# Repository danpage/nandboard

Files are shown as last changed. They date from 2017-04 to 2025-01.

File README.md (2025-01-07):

# NANDboard: hands-on Boolean algebra

<!--- -------------------------------------------------------------------- --->

## History

Starting in the 2012/13 academic year, the
[Computer Science Department](http://www.cs.bris.ac.uk)
at the
[University of Bristol](http://www.bris.ac.uk)
changed how the Undergraduate-level, 1st year (or "freshman") Computer
Architecture unit was delivered.  Although it *always* had a practical
emphasis, there was a view it should be even more hands-on.
There were various motivations, included the fact that
a) by doing so the topic could be more engaging,
   but also
b) it seeds an ethos and skills that are of general use: for example,
   it could mean students participate more actively in
   [maker-like](http://en.wikipedia.org/wiki/Maker_culture),
   hardware-based (versus software-only) projects.

The NANDboard, whose original concept and design was due to
[Simon Hollis](https://github.com/simonhollis),
was among various innovations introduced; Simon left at the end of the
2014/15 academic year, ~~prompting~~ forcing me to learn the basics of
PCB design and subsequently revise his initial NANDboard version.

<!--- -------------------------------------------------------------------- --->

## Concept

Although fundamentally important in Computer Science,
[Boolean algebra](http://en.wikipedia.org/wiki/Boolean_algebra)
is a notoriously dry topic.  The problem is exacerbated when hands-on 
experience amounts to solving paper-and-pencil exercises; the typical
result is for students to be increasingly uninterested and disengaged.
The underlying causes are varied, and differ from student to student.
However, anecdotally at least, the following are common:

- There is a disconnection between theory and practice, in the sense
  it is unclear how Boolean algebra directly relates to intuitively 
  useful forms of computation;
  this typically leads to students disengaging,
  based on the view that said theory has no practical use (to them).
- Paper-and-pencil exercises are of a necessarily small scale, which
  can mean 
  [toy problems](http://en.wikipedia.org/wiki/Toy_problem)
  dominate; 
  this typically leads to students disengaging, e.g., because they
  can easily solve said problems so avoid any deeper investigation
  of physical constraints and properties, and unusual designs
  (e.g., a [C-element](https://en.wikipedia.org/wiki/C-element)).
- In part due to the wealth of resources available, modern students 
  are used to and excited by the immediacy of software development;
  this is often direct motivation for studying Computer Science in 
  the first place, with Boolean algebra feeling like a regression 
  towards Mathematics (which, for some, is less popular).

Put another way, this approach is similar, by analogy, to learning
[C](http://en.wikipedia.org/wiki/C_(programming_language))
by studying the language and 
["hello world"](https://en.wikipedia.org/wiki/"Hello,_World!"_program)
style programs *without* ever actually compiling and executing them.

An obvious alternative is to connect theory and practice directly, by
supporting genuinely hands-on, experimental tasks.  One way to do so
might be to equip each student with a breadboard and some
[7400 series](https://en.wikipedia.org/wiki/List_of_7400_series_integrated_circuits)
ICs.  However, for us at least, this presented some problems:
a) large cohort sizes
   (of say 200+ students)
   make the logistics involved quite challenging,
b) said cohorts are typically unfamiliar with, and sometimes have an
   outright dislike for electronics.
The NANDboard attempts to manage these problems.  Conceptually, it is 
just a USB-powered breadboard pre-populated with NAND gates: it could
be viewed as a form of NAND-only
[PLA](http://en.wikipedia.org/wiki/Programmable_logic_array),
where implementation of a Boolean expression (cf. programming the PLA)
amounts to connecting pin headers (i.e., the gate inputs and outputs)
using jumper wire.  There are, of course, some gratuitous
[blinkenlights](http://en.wikipedia.org/wiki/Blinkenlights)
to visualise the inputs and outputs.

<!--- -------------------------------------------------------------------- --->

## Design

Motivated in part by observing how students use them, the NANDboard 
design has gone through several revisions as is illustrated below:

Revision | Image                                                                             | Design                                                                             |
:------: | :-------------------------------------------------------------------------------: | :--------------------------------------------------------------------------------: |
B        |  |                                                                                    |
C        |  |                                                                                    |
D        |  | [files](./rev_d), [schematic](./rev_d/README.pdf), [user guide](./rev_d/README.md) |
F        |  | [files](./rev_f), [schematic](./rev_f/README.pdf), [user guide](./rev_f/README.md) |

<!--- -------------------------------------------------------------------- --->

## Acknowledgements

Later revisions 
(e.g., rev. F) 
were designed and manufactured with generous support from 
[Elliptic Systems](https://elliptic-systems.com).

<!--- -------------------------------------------------------------------- --->

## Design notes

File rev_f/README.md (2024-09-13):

<!--- -------------------------------------------------------------------- --->

# High-level structure

At a high level, (the top-side of) a given 
NANDboard
is organised into a set of somewhat groups (or regions) reflected 
by annotation on the 
[PCB](https://en.wikipedia.org/wiki/Printed_circuit_board):

```
+----------+----------+----------+----------+----------+
|    input |     NAND |     NAND |   output |    power |
|    group |    group |    group |    group |    group |
|          |       #0 |       #1 |          |          |
|          +----------+----------+          |          |~~~~ USB
|          |     NAND |     NAND |          |          |
|          |    group |    group |          |          |
|          |       #2 |       #3 |          |          |
+----------+----------+----------+----------+----------+
```

Each group designed to support a specific purpose, as explained
in detail below.  Again
at a high level,
however, use of the 
NANDboard 
can be summarised as follows.  Imagine you are tasked with using 
a
NANDboard
to implement some 4-input, 1-output Boolean function
`R = f( X_0, X_1, X_2, X_3 )`
To do so, the idea is you

- use the  input group  to model (and   control) the  input, 
- use the   NAND groups to implement `f` by decomposing it into a NAND-based expression,
- use the output group  to model (and visualise) the output, 
  
using
[jumper wire](https://en.wikipedia.org/wiki/Jump_wire)
to form connections to inputs, outputs, and between intermediate 
signals.

<!--- -------------------------------------------------------------------- --->

# Low-level detail

### The power    group

Viewed from top-to-bottom,
the  power  group comprises

- an 8x2          [pin header](https://en.wikipedia.org/wiki/Pin_header),
- a type-C [USB](https://en.wikipedia.org/wiki/USB) connector,
- an 8x2          [pin header](https://en.wikipedia.org/wiki/Pin_header).

The basic idea is that:

- The USB connector 
  supplies the 
  NANDboard 
  with power from some host (e.g., a workstation).
- The pin headers allow multiple 
  NANDboards 
  to be
  ["daisy-chained"](https://en.wikipedia.org/wiki/Daisy_chain_(electrical_engineering))
  together, e.g., to implement larger, more complex designs: doing
  so basically means 
  
  - supplying *one*
    "powered"  NANDboard 
    with power via the USB connector
  - supplying *other*
    "tethered" NANDboards
    with power via their pin headers by connecting their
     [5V](https://en.wikipedia.org/wiki/Volt)
    and
    [GND](https://en.wikipedia.org/wiki/Ground_(electricity))
    pins to those of the
    "powered"  NANDboard.

  This demands care, however, because misconnection can potentially 
  damage the board and/or workstation: the safest approach would be
  to cover the pins with
  [jumpers](https://en.wikipedia.org/wiki/Jumper_(computing))
  when not in use.

### The input    group

Viewed from left-to-right, 
the   input group comprises

- 4 [switches](http://en.wikipedia.org/wiki/Switch) (or buttons),
  and
- an 8x2          [pin header](https://en.wikipedia.org/wiki/Pin_header).

so can be thought of conceptually as the following block diagram:
   
```
switches           pins 
 __|__         _____|_____ 
/     \       /           \
               +-----+-----+
+-----+       | X_0 | X_0 |
| X_0 | ~~~>  +-----+-----+
+-----+       | X_0 | X_0 |
              +-----+-----+
+-----+       | X_1 | X_1 |
| X_1 | ~~~>  +-----+-----+
+-----+       | X_1 | X_1 |
              +-----+-----+
+-----+       | X_2 | X_2 |
| X_2 | ~~~>  +-----+-----+
+-----+       | X_2 | X_2 |
              +-----+-----+
+-----+       | X_3 | X_3 |
| X_3 | ~~~>  +-----+-----+
+-----+       | X_3 | X_3 |
              +-----+-----+
```

The basic idea is that
each switch is connected to a group of 4 pins:
the state of each group of pins (i.e., 0 or 1)
is determined by
that of the associated switch,
so when the switch is pressed (resp. not pressed) the pins will be 1 (resp. 0).

### The output   group

Viewed from left-to-right, 
the  output group comprises

- an 8x2          [pin header](https://en.wikipedia.org/wiki/Pin_header),
  and
- 4 [LEDs](https://en.wikipedia.org/wiki/Light-emitting_diode).

```
     pins            LEDs
 _____|_____        __|__
/           \      /     \

+-----+-----+
| R_0 | R_0 |      +-----+
+-----+-----+ ~~~> | R_0 |
| R_0 | R_0 |      +-----+
+-----+-----+
| R_1 | R_1 |      +-----+
+-----+-----+ ~~~> | R_1 | 
| R_1 | R_1 |      +-----+
+-----+-----+
| R_2 | R_2 |      +-----+
+-----+-----+ ~~~> | R_2 |
| R_2 | R_2 |      +-----+
+-----+-----+
| R_3 | R_3 |      +-----+
+-----+-----+ ~~~> | R_3 |
| R_3 | R_3 |      +-----+
+-----+-----+
```

The basic idea is that
each LED    is connected to a group of 4 pins:
the state of each group of pins (i.e., 0 or 1)
determines
that of the associated LED,
so when the pins are 1 (resp. 0) the LED will be on (resp. off).

## The NAND     group(s)

Viewed from left-to-right, 
each NAND   group comprises

- an 4x2 constant [pin header](https://en.wikipedia.org/wiki/Pin_header),
- an 8x2    input [pin header](https://en.wikipedia.org/wiki/Pin_header),
- an [IC](http://www.ti.com/lit/gpn/sn74ac00) that houses 4 [NAND gates](https://en.wikipedia.org/wiki/NAND_gate),
- an 8x2   output [pin header](https://en.wikipedia.org/wiki/Pin_header).
  and
- 4 [LEDs](https://en.wikipedia.org/wiki/Light-emitting_diode).

so can be thought of conceptually as the following block diagram:

```
constant pins
 _____|_____
/           \

+-----+-----+
|  1  |  1  |
+-----+-----+
|  1  |  1  |
+-----+-----+

 input pins                NAND gates             output pins         LEDs
 _____|_____        ___________|__________        _____|_____        __|__
/           \      /                      \      /           \      /     \

+-----+-----+      +----------------------+      +-----+-----+
| x_0 | x_0 | ~~~> |                      |      | r_0 | r_0 |      +-----+
+-----+-----+      | r_0 = ~( x_0 & y_0 ) | ~~~> +-----+-----+ ~~~> | r_0 |
| y_0 | y_0 | ~~~> |                      |      | r_0 | r_0 |      +-----+
+-----+-----+      |                      |      +-----+-----+
| x_1 | x_1 | ~~~> |                      |      | r_1 | r_1 |      +-----+
+-----+-----+      | r_1 = ~( x_1 & y_1 ) | ~~~> +-----+-----+ ~~~> | r_1 |
| y_1 | y_1 | ~~~> |                      |      | r_1 | r_1 |      +-----+
+-----+-----+      |                      |      +-----+-----+
| x_2 | x_2 | ~~~> |                      |      | r_2 | r_2 |      +-----+
+-----+-----+      | r_2 = ~( x_2 & y_2 ) | ~~~> +-----+-----+ ~~~> | r_2 |
| y_2 | y_2 | ~~~> |                      |      | r_2 | r_2 |      +-----+
+-----+-----+      |                      |      +-----+-----+
| x_3 | x_3 | ~~~> |                      |      | r_3 | r_3 |      +-----+
+-----+-----+      | r_3 = ~( x_3 & y_3 ) | ~~~> +-----+-----+ ~~~> | r_3 |
| y_3 | y_3 | ~~~> |                      |      | r_3 | r_3 |      +-----+
+-----+-----+      +----------------------+      +-----+-----+
```
   
The basic idea is that:

- Each group houses 4 replicated instances of the same structure,
  the `i`-th of which computes 
  `r_i = ~( x_i & y_i )`.
  We use on the 0-th, top-most instance as an example throughout
  the following.  

- The computation of
  `r_0 = ~( x_0 & y_0 )`
  relates to the top 4 pins (i.e., top 2 rows) of both the input
  and output pins headers: the input pins marked `x_0` and `y_0` 
  provided an input to the NAND gate, which produces a result 
  reflected on the output pins marked `r_0`.  
  Each output pin is also connected to an LED, allowing the state
  (i.e., 0 or 1) to be visualised.

- Note there are 2 pins marked `x_0` and `y_0` on the input pin
  header: since they are connected together, either of the 2 pins
  (i.e., the left- *or* right-hand pin marked `x_0`) can be used 
  to provide the associated input.  Likewise, there are 4 pins
  marked `r_0` on the output pin header: the NAND gate output is
  replicated on each of those pins.

- Each input pin is 
  [pulled-down](http://en.wikipedia.org/wiki/Pull-up_resistor), 
  meaning that `x_0` and `y_0` are 0 and `r_0` is 1 by default.
  However, an input pin can be freely connected (via jumper wire)
  to any other

  - constant           pin,
  - input group        pin,
  - NAND  group input  pin,
  - NAND  group output pin

  elsewhere on the NANDboard.

- Since each input pin is 0-by-default, the constant pins can be
  used to "override" this.  Imagine that rather than
  `r_0 = ~( x_0 & y_0 )`,
  you need to compute
  `r_0 = ~( x_0 & 1   )`
  for some reason: a reasonable approach is to connect the `y_0` 
  input pin of the NAND gate to one of the 1-by-default constant
  pins.

- The NAND groups and hence operators are independent, meaning 
  you can form inter- and intra-group connections (i.e., inside 
  one group and between two groups).

### Misc.

The bottom-side of the
NANDboard
includes a
10-pin [TagConnect](https://www.tag-connect.com)
header: those pins connect to

- the 
  [5V](https://en.wikipedia.org/wiki/Volt)
  and
  [GND](https://en.wikipedia.org/wiki/Ground_(electricity))
  pins in the  power group,
- each 
  pin  in the  input group, i.e., `X_0`, `X_1`, `X_2`, and `X_3`,
  and
- each 
  pin  in the output group, i.e., `R_0`, `R_1`, `R_2`, and `R_3`.

By connecting the
NANDboard
to a host using a compliant
[pogo-pin](https://en.wikipedia.org/wiki/Pogo_pin) 
style cable, one can therefore programmatically control input to
and inspect output generated by it; an example use-case would be
to automatically, and exhaustively test whether the
NANDboard 
correctly implements a given function.

<!--- -------------------------------------------------------------------- --->

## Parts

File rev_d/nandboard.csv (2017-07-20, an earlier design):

Qty | Line Item | Manufacturer | Schematic Reference | Description
4 | SN74AC00DR | Texas Instruments | IC1.1, IC2.1, IC3.1, IC4.1 | quad 2-input NAND; SOIC-14
4 | B3FS-1000P | Omron | SI.1, SI.2, SI.3, SI.4 | SPST switch
1 | 10103594-0001LF | FCI | USB | USB receptacle
9 | M20-8760842 | Harwin | J1.1, J1.2, J2.1, J2.2, J3.1, J3.2, J4.1, J4.2, JI.1 | 8x2 male header
4 | M20-8770842 | Harwin | J1.3, J2.3, J3.3, J4.3 | 8x1 male header
16 | APT2012SGC | Kingbright | D1.1, D1.2, D1.3, D1.4, D2.1, D2.2, D2.3, D2.4, D3.1, D3.2, D3.3, D3.4, D4.1, D4.2, D4.3, D4.4 | green LED; 0805
1 | C1210C107M9PACTU | KEMET | CP.1 | 100 uF capacitor; 1210
1 | C0805C104K3RACTU | KEMET | CP.2 | 100 nF = 0.1 uF capacitor; 0805
4 | 742C163103JP | CTS Components | R1.1, R2.1, R3.1, R4.1 | 8x10k ohm resistor array; 2506
1 | 742C083103JP | CTS Components | RI.1 | 4x10k ohm resistor array; 1206
4 | 742C083561JP | CTS Components | R1.2, R2.2, R3.2, R4.2 | 4x560 ohm resistor array; 1206
4 | 742C083102JP | CTS Components | R1.3, R2.3, R3.3, R4.3 | 4x1k ohm resistor array; 1206

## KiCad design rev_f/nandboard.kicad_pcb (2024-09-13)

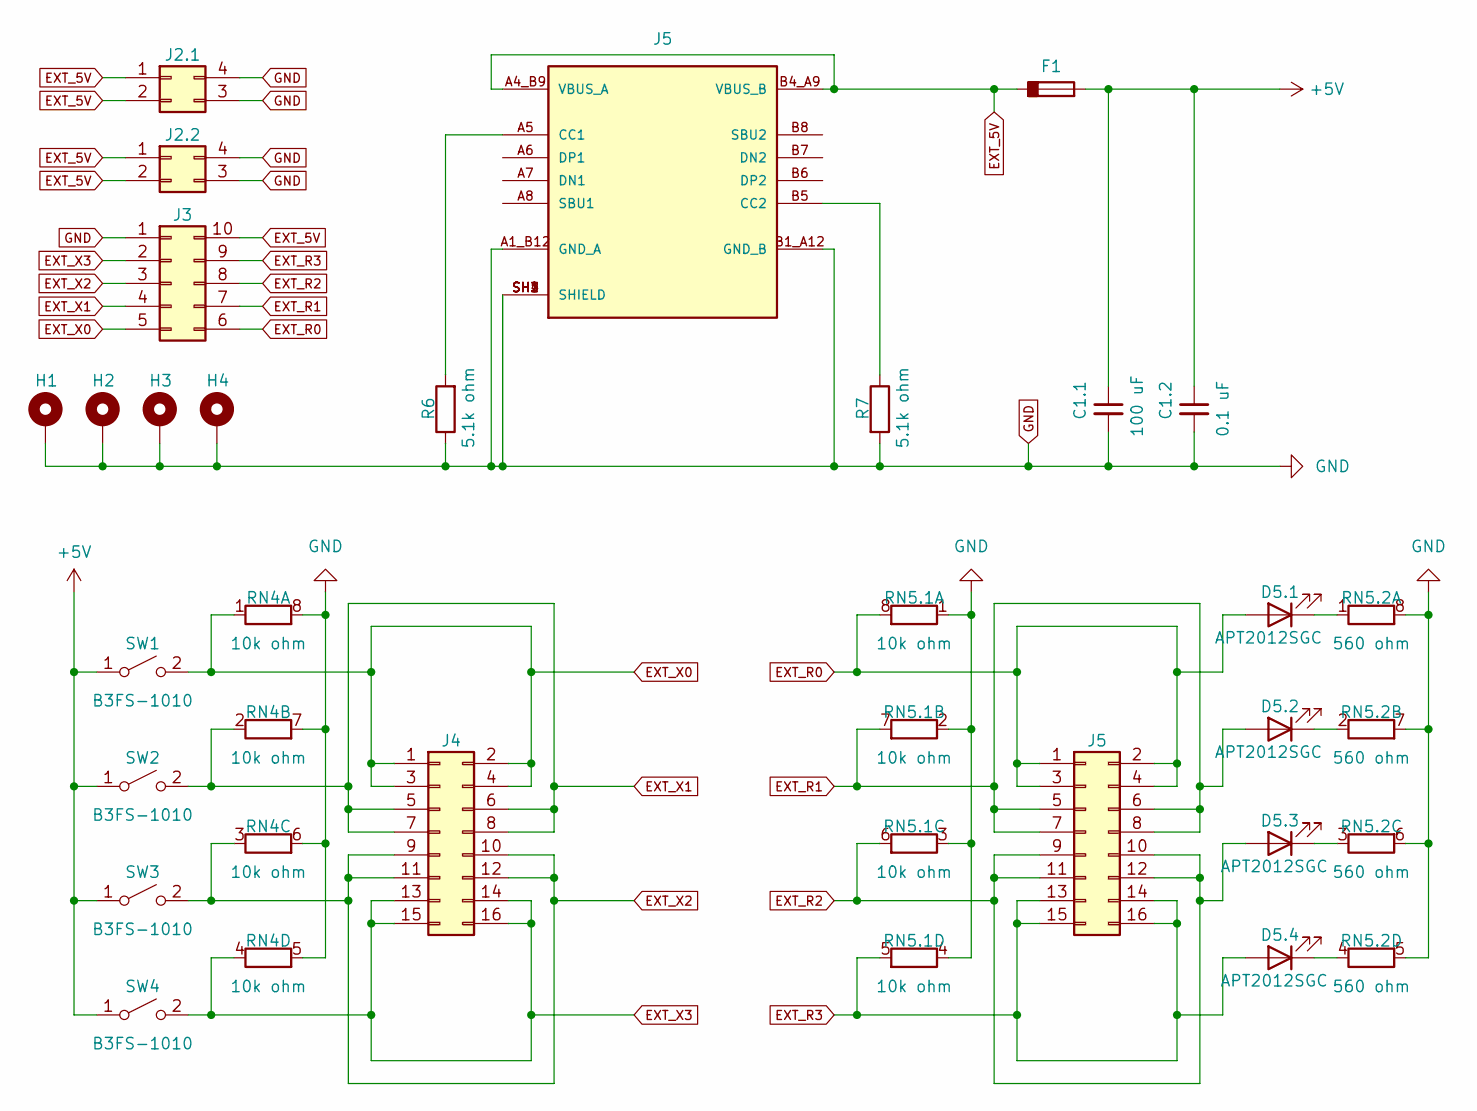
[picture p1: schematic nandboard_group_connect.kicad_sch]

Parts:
C1.1: 100 uF; C_1210_3225Metric
C1.2: 0.1 uF; C_0805_2012Metric
D5.1, D5.2, D5.3, D5.4: APT2012SGC; LED_0805_2012Metric
F1: Fuse_Polarized; Fuse_1206_3216Metric
H1, H2, H3, H4: MountingHole_Pad; MountingHole_3.2mm_M3_Pad
J2.1, J2.2: Conn_02x02_Counter_Clockwise; PinHeader_2x02_P2.54mm_Vertical_SMD
J3: Conn_02x05_Counter_Clockwise; Tag-Connect_TC2050-IDC-NL_2x05_P1.27mm_Vertical
J4: Conn_02x08_Odd_Even; PinHeader_2x08_P2.54mm_Vertical_SMD
J5: USB_C_Receptacle_USB2.0; AMPHENOL_GSB1C41110SSHR; Mouser Part Number 523-GSB1C41110SSHR
R6, R7: 5.1k ohm; R_0603_1608Metric; Mouser Part Number 755-SFR18EZPF5101
RN4, RN5.1: 10k ohm; RN-1206-Convex-LongSideTerminals
RN5.2: 560 ohm; RN-1206-Convex-LongSideTerminals
SW1, SW2, SW3, SW4: B3FS-1010; SW_SPST_Omron_B3FS-101xP

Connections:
+5V: C1.1.1, C1.2.1, F1.2, SW1.1 (A), SW2.1 (A), SW3.1 (A), SW4.1 (A); also elsewhere on the board
EXT_5V: F1.1, J2.1.1, J2.1.2, J2.2.1, J2.2.2, J3.10, J5.A4_B9 (VBUS_A), J5.B4_A9 (VBUS_B); also elsewhere on the board
EXT_R0: D5.1.2 (A), J3.6, J5.1, J5.2, J5.3, J5.4, RN5.1.8 (R1.2)
EXT_R1: D5.2.2 (A), J3.7, J5.5, J5.6, J5.7, J5.8, RN5.1.7 (R2.2)
EXT_R2: D5.3.2 (A), J3.8, J5.9, J5.10, J5.11, J5.12, RN5.1.6 (R3.2)
EXT_R3: D5.4.2 (A), J3.9, J5.13, J5.14, J5.15, J5.16, RN5.1.5 (R4.2)
EXT_X0: J3.5, J4.1, J4.2, J4.3, J4.4, RN4.1 (R1.1), SW1.2 (B)
EXT_X1: J3.4, J4.5, J4.6, J4.7, J4.8, RN4.2 (R2.1), SW2.2 (B)
EXT_X2: J3.3, J4.9, J4.10, J4.11, J4.12, RN4.3 (R3.1), SW3.2 (B)
EXT_X3: J3.2, J4.13, J4.14, J4.15, J4.16, RN4.4 (R4.1), SW4.2 (B)
GND: C1.1.2, C1.2.2, H1.1, H2.1, H3.1, H4.1, J2.1.3, J2.1.4, J2.2.3, J2.2.4, J3.1, J5.A1_B12 (GND_A), J5.B1_A12 (GND_B), J5.SH1 (SHIELD), J5.SH2 (SHIELD), J5.SH3 (SHIELD), J5.SH4 (SHIELD), RN4.5 (R4.2), RN4.6 (R3.2), RN4.7 (R2.2), RN4.8 (R1.2), RN5.1.1 (R1.1), RN5.1.2 (R2.1), RN5.1.3 (R3.1), RN5.1.4 (R4.1), RN5.2.5 (R4.2), RN5.2.6 (R3.2), RN5.2.7 (R2.2), RN5.2.8 (R1.2); also elsewhere on the board
unnamed: D5.1.1 (K), RN5.2.1 (R1.1)
unnamed: D5.2.1 (K), RN5.2.2 (R2.1)
unnamed: D5.3.1 (K), RN5.2.3 (R3.1)
unnamed: D5.4.1 (K), RN5.2.4 (R4.1)

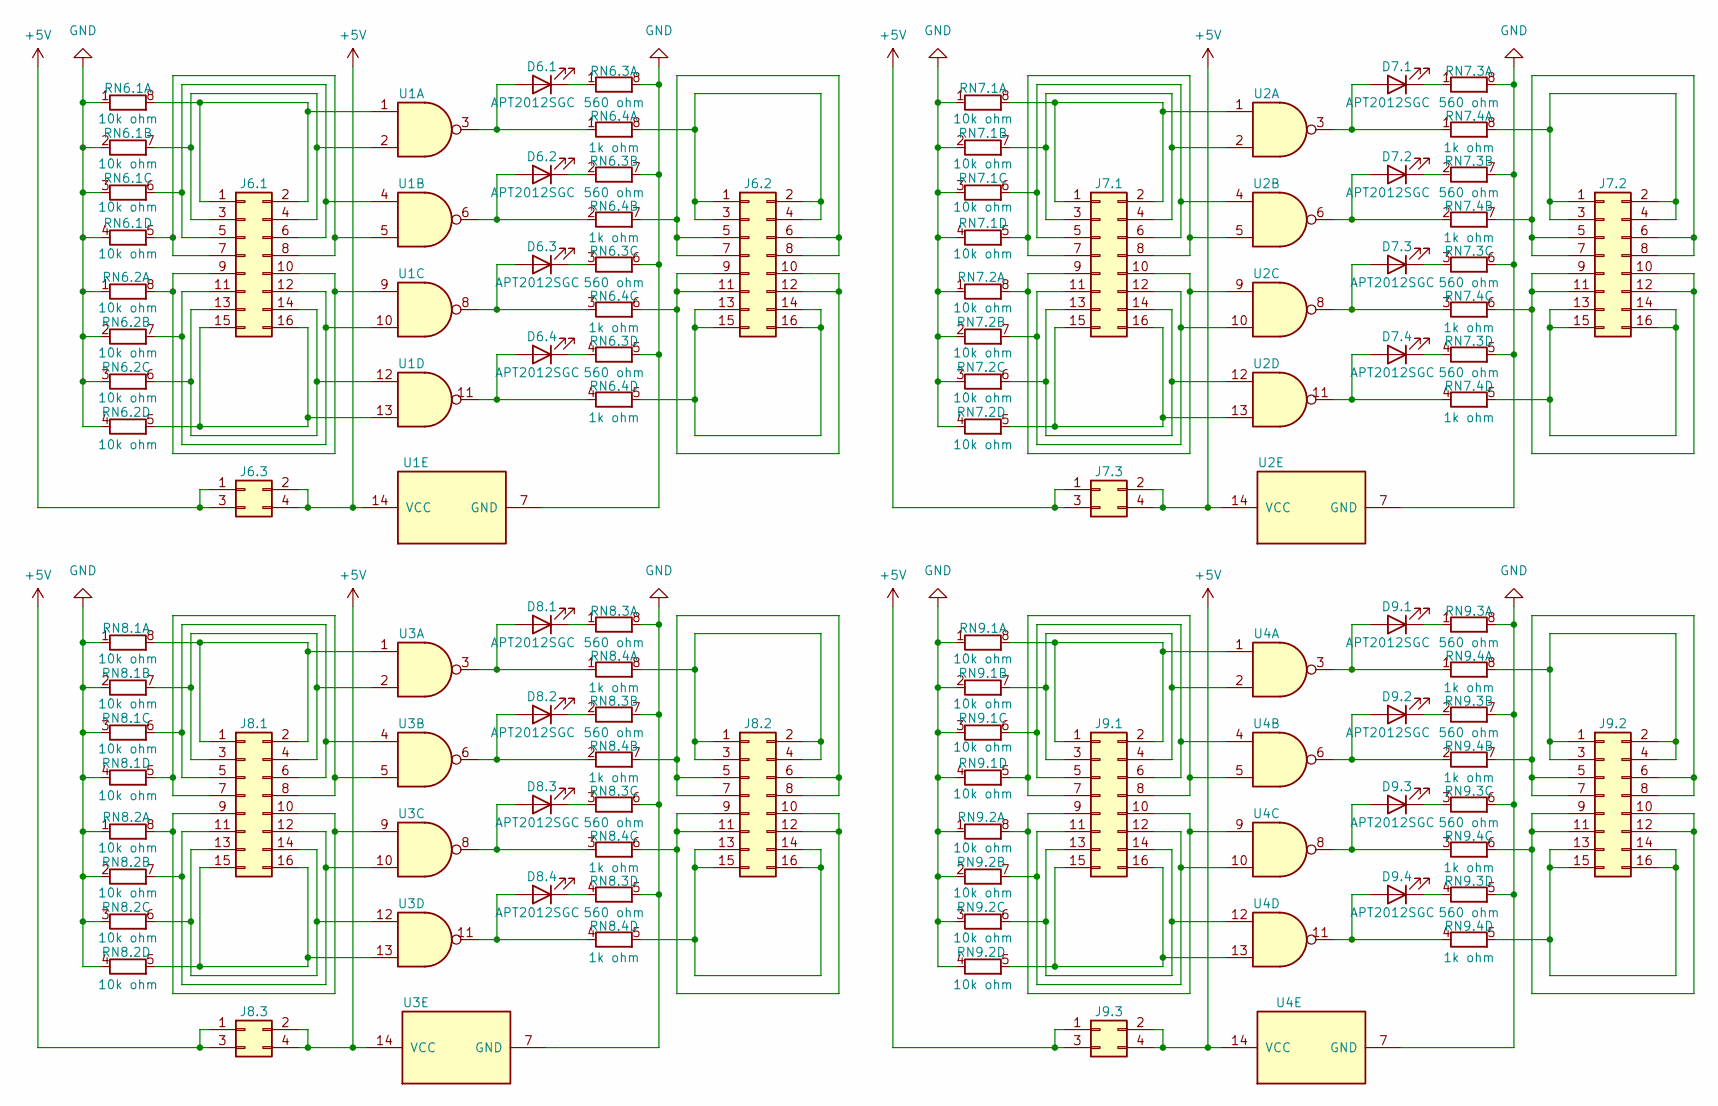
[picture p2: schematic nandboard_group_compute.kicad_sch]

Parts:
D6.1, D6.2, D6.3, D6.4, D7.1, D7.2, D7.3, D7.4, D8.1, D8.2, D8.3, D8.4, D9.1, D9.2, D9.3, D9.4: APT2012SGC; LED_0805_2012Metric
J6.1, J6.2, J7.1, J7.2, J8.1, J8.2, J9.1, J9.2: Conn_02x08_Odd_Even; PinHeader_2x08_P2.54mm_Vertical_SMD
J6.3, J7.3, J8.3, J9.3: Conn_02x02_Odd_Even; PinHeader_2x02_P2.54mm_Vertical_SMD
RN6.1, RN6.2, RN7.1, RN7.2, RN8.1, RN8.2, RN9.1, RN9.2: 10k ohm; RN-1206-Convex-LongSideTerminals
RN6.3, RN7.3, RN8.3, RN9.3: 560 ohm; RN-1206-Convex-LongSideTerminals
RN6.4, RN7.4, RN8.4, RN9.4: 1k ohm; RN-1206-Convex-LongSideTerminals
U1, U2, U3, U4: 7400; SOIC-14_3.9x8.7mm_P1.27mm

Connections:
+5V: J6.3.1, J6.3.2, J6.3.3, J6.3.4, J7.3.1, J7.3.2, J7.3.3, J7.3.4, J8.3.1, J8.3.2, J8.3.3, J8.3.4, J9.3.1, J9.3.2, J9.3.3, J9.3.4, U1.14 (VCC), U2.14 (VCC), U3.14 (VCC), U4.14 (VCC); also elsewhere on the board
GND: RN6.1.1 (R1.1), RN6.1.2 (R2.1), RN6.1.3 (R3.1), RN6.1.4 (R4.1), RN6.2.1 (R1.1), RN6.2.2 (R2.1), RN6.2.3 (R3.1), RN6.2.4 (R4.1), RN6.3.5 (R4.2), RN6.3.6 (R3.2), RN6.3.7 (R2.2), RN6.3.8 (R1.2), RN7.1.1 (R1.1), RN7.1.2 (R2.1), RN7.1.3 (R3.1), RN7.1.4 (R4.1), RN7.2.1 (R1.1), RN7.2.2 (R2.1), RN7.2.3 (R3.1), RN7.2.4 (R4.1), RN7.3.5 (R4.2), RN7.3.6 (R3.2), RN7.3.7 (R2.2), RN7.3.8 (R1.2), RN8.1.1 (R1.1), RN8.1.2 (R2.1), RN8.1.3 (R3.1), RN8.1.4 (R4.1), RN8.2.1 (R1.1), RN8.2.2 (R2.1), RN8.2.3 (R3.1), RN8.2.4 (R4.1), RN8.3.5 (R4.2), RN8.3.6 (R3.2), RN8.3.7 (R2.2), RN8.3.8 (R1.2), RN9.1.1 (R1.1), RN9.1.2 (R2.1), RN9.1.3 (R3.1), RN9.1.4 (R4.1), RN9.2.1 (R1.1), RN9.2.2 (R2.1), RN9.2.3 (R3.1), RN9.2.4 (R4.1), RN9.3.5 (R4.2), RN9.3.6 (R3.2), RN9.3.7 (R2.2), RN9.3.8 (R1.2), U1.7 (GND), U2.7 (GND), U3.7 (GND), U4.7 (GND); also elsewhere on the board
unnamed: D6.1.2 (A), RN6.4.1 (R1.1), U1.3
unnamed: D6.1.1 (K), RN6.3.1 (R1.1)
unnamed: D6.2.2 (A), RN6.4.2 (R2.1), U1.6
unnamed: D6.2.1 (K), RN6.3.2 (R2.1)
unnamed: D6.3.2 (A), RN6.4.3 (R3.1), U1.8
unnamed: D6.3.1 (K), RN6.3.3 (R3.1)
unnamed: D6.4.2 (A), RN6.4.4 (R4.1), U1.11
unnamed: D6.4.1 (K), RN6.3.4 (R4.1)
unnamed: D7.1.2 (A), RN7.4.1 (R1.1), U2.3
unnamed: D7.1.1 (K), RN7.3.1 (R1.1)
unnamed: D7.2.2 (A), RN7.4.2 (R2.1), U2.6
unnamed: D7.2.1 (K), RN7.3.2 (R2.1)
unnamed: D7.3.2 (A), RN7.4.3 (R3.1), U2.8
unnamed: D7.3.1 (K), RN7.3.3 (R3.1)
unnamed: D7.4.2 (A), RN7.4.4 (R4.1), U2.11
unnamed: D7.4.1 (K), RN7.3.4 (R4.1)
unnamed: D8.1.2 (A), RN8.4.1 (R1.1), U3.3
unnamed: D8.1.1 (K), RN8.3.1 (R1.1)
unnamed: D8.2.2 (A), RN8.4.2 (R2.1), U3.6
unnamed: D8.2.1 (K), RN8.3.2 (R2.1)
unnamed: D8.3.2 (A), RN8.4.3 (R3.1), U3.8
unnamed: D8.3.1 (K), RN8.3.3 (R3.1)
unnamed: D8.4.2 (A), RN8.4.4 (R4.1), U3.11
unnamed: D8.4.1 (K), RN8.3.4 (R4.1)
unnamed: D9.1.2 (A), RN9.4.1 (R1.1), U4.3
unnamed: D9.1.1 (K), RN9.3.1 (R1.1)
unnamed: D9.2.2 (A), RN9.4.2 (R2.1), U4.6
unnamed: D9.2.1 (K), RN9.3.2 (R2.1)
unnamed: D9.3.2 (A), RN9.4.3 (R3.1), U4.8
unnamed: D9.3.1 (K), RN9.3.3 (R3.1)
unnamed: D9.4.2 (A), RN9.4.4 (R4.1), U4.11
unnamed: D9.4.1 (K), RN9.3.4 (R4.1)
unnamed: J6.1.1, J6.1.2, RN6.1.8 (R1.2), U1.1
unnamed: J6.1.3, J6.1.4, RN6.1.7 (R2.2), U1.2
unnamed: J6.1.5, J6.1.6, RN6.1.6 (R3.2), U1.4
unnamed: J6.1.7, J6.1.8, RN6.1.5 (R4.2), U1.5
unnamed: J6.1.9, J6.1.10, RN6.2.8 (R1.2), U1.9
unnamed: J6.1.11, J6.1.12, RN6.2.7 (R2.2), U1.10
unnamed: J6.1.13, J6.1.14, RN6.2.6 (R3.2), U1.12
unnamed: J6.1.15, J6.1.16, RN6.2.5 (R4.2), U1.13
unnamed: J6.2.1, J6.2.2, J6.2.3, J6.2.4, RN6.4.8 (R1.2)
unnamed: J6.2.5, J6.2.6, J6.2.7, J6.2.8, RN6.4.7 (R2.2)
unnamed: J6.2.9, J6.2.10, J6.2.11, J6.2.12, RN6.4.6 (R3.2)
unnamed: J6.2.13, J6.2.14, J6.2.15, J6.2.16, RN6.4.5 (R4.2)
unnamed: J7.1.1, J7.1.2, RN7.1.8 (R1.2), U2.1
unnamed: J7.1.3, J7.1.4, RN7.1.7 (R2.2), U2.2
unnamed: J7.1.5, J7.1.6, RN7.1.6 (R3.2), U2.4
unnamed: J7.1.7, J7.1.8, RN7.1.5 (R4.2), U2.5
unnamed: J7.1.9, J7.1.10, RN7.2.8 (R1.2), U2.9
unnamed: J7.1.11, J7.1.12, RN7.2.7 (R2.2), U2.10
unnamed: J7.1.13, J7.1.14, RN7.2.6 (R3.2), U2.12
unnamed: J7.1.15, J7.1.16, RN7.2.5 (R4.2), U2.13
unnamed: J7.2.1, J7.2.2, J7.2.3, J7.2.4, RN7.4.8 (R1.2)
unnamed: J7.2.5, J7.2.6, J7.2.7, J7.2.8, RN7.4.7 (R2.2)
unnamed: J7.2.9, J7.2.10, J7.2.11, J7.2.12, RN7.4.6 (R3.2)
unnamed: J7.2.13, J7.2.14, J7.2.15, J7.2.16, RN7.4.5 (R4.2)
unnamed: J8.1.1, J8.1.2, RN8.1.8 (R1.2), U3.1
unnamed: J8.1.3, J8.1.4, RN8.1.7 (R2.2), U3.2
unnamed: J8.1.5, J8.1.6, RN8.1.6 (R3.2), U3.4
unnamed: J8.1.7, J8.1.8, RN8.1.5 (R4.2), U3.5
unnamed: J8.1.9, J8.1.10, RN8.2.8 (R1.2), U3.9
unnamed: J8.1.11, J8.1.12, RN8.2.7 (R2.2), U3.10
unnamed: J8.1.13, J8.1.14, RN8.2.6 (R3.2), U3.12
unnamed: J8.1.15, J8.1.16, RN8.2.5 (R4.2), U3.13
unnamed: J8.2.1, J8.2.2, J8.2.3, J8.2.4, RN8.4.8 (R1.2)
unnamed: J8.2.5, J8.2.6, J8.2.7, J8.2.8, RN8.4.7 (R2.2)
unnamed: J8.2.9, J8.2.10, J8.2.11, J8.2.12, RN8.4.6 (R3.2)
unnamed: J8.2.13, J8.2.14, J8.2.15, J8.2.16, RN8.4.5 (R4.2)
unnamed: J9.1.1, J9.1.2, RN9.1.8 (R1.2), U4.1
unnamed: J9.1.3, J9.1.4, RN9.1.7 (R2.2), U4.2
unnamed: J9.1.5, J9.1.6, RN9.1.6 (R3.2), U4.4
unnamed: J9.1.7, J9.1.8, RN9.1.5 (R4.2), U4.5
unnamed: J9.1.9, J9.1.10, RN9.2.8 (R1.2), U4.9
unnamed: J9.1.11, J9.1.12, RN9.2.7 (R2.2), U4.10
unnamed: J9.1.13, J9.1.14, RN9.2.6 (R3.2), U4.12
unnamed: J9.1.15, J9.1.16, RN9.2.5 (R4.2), U4.13
unnamed: J9.2.1, J9.2.2, J9.2.3, J9.2.4, RN9.4.8 (R1.2)
unnamed: J9.2.5, J9.2.6, J9.2.7, J9.2.8, RN9.4.7 (R2.2)
unnamed: J9.2.9, J9.2.10, J9.2.11, J9.2.12, RN9.4.6 (R3.2)
unnamed: J9.2.13, J9.2.14, J9.2.15, J9.2.16, RN9.4.5 (R4.2)

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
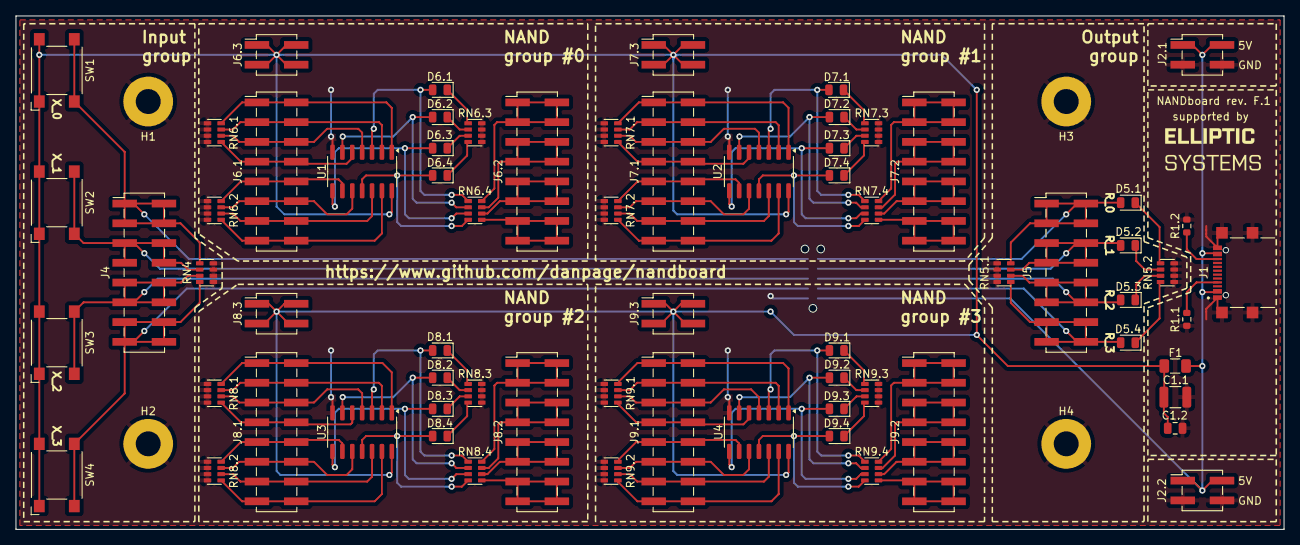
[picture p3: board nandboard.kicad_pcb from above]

Board: 2 copper layers, 163.0 x 66.0 mm, 74 parts (1 on the bottom side), 97 nets.

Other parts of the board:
J1: USB_C_Receptacle_USB2.0; AMPHENOL_GSB1C41110SSHR
R1.1, R1.2: 5.1k ohm; R_0603_1608Metric

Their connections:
EXT_5V: J1.A4_B9 (VBUS_A), J1.B4_A9 (VBUS_B); also elsewhere on the board
GND: J1.A1_B12 (GND_A), J1.B1_A12 (GND_B), J1.SH1 (SHIELD), J1.SH2 (SHIELD), J1.SH3 (SHIELD), J1.SH4 (SHIELD), R1.1.1, R1.2.2; also elsewhere on the board

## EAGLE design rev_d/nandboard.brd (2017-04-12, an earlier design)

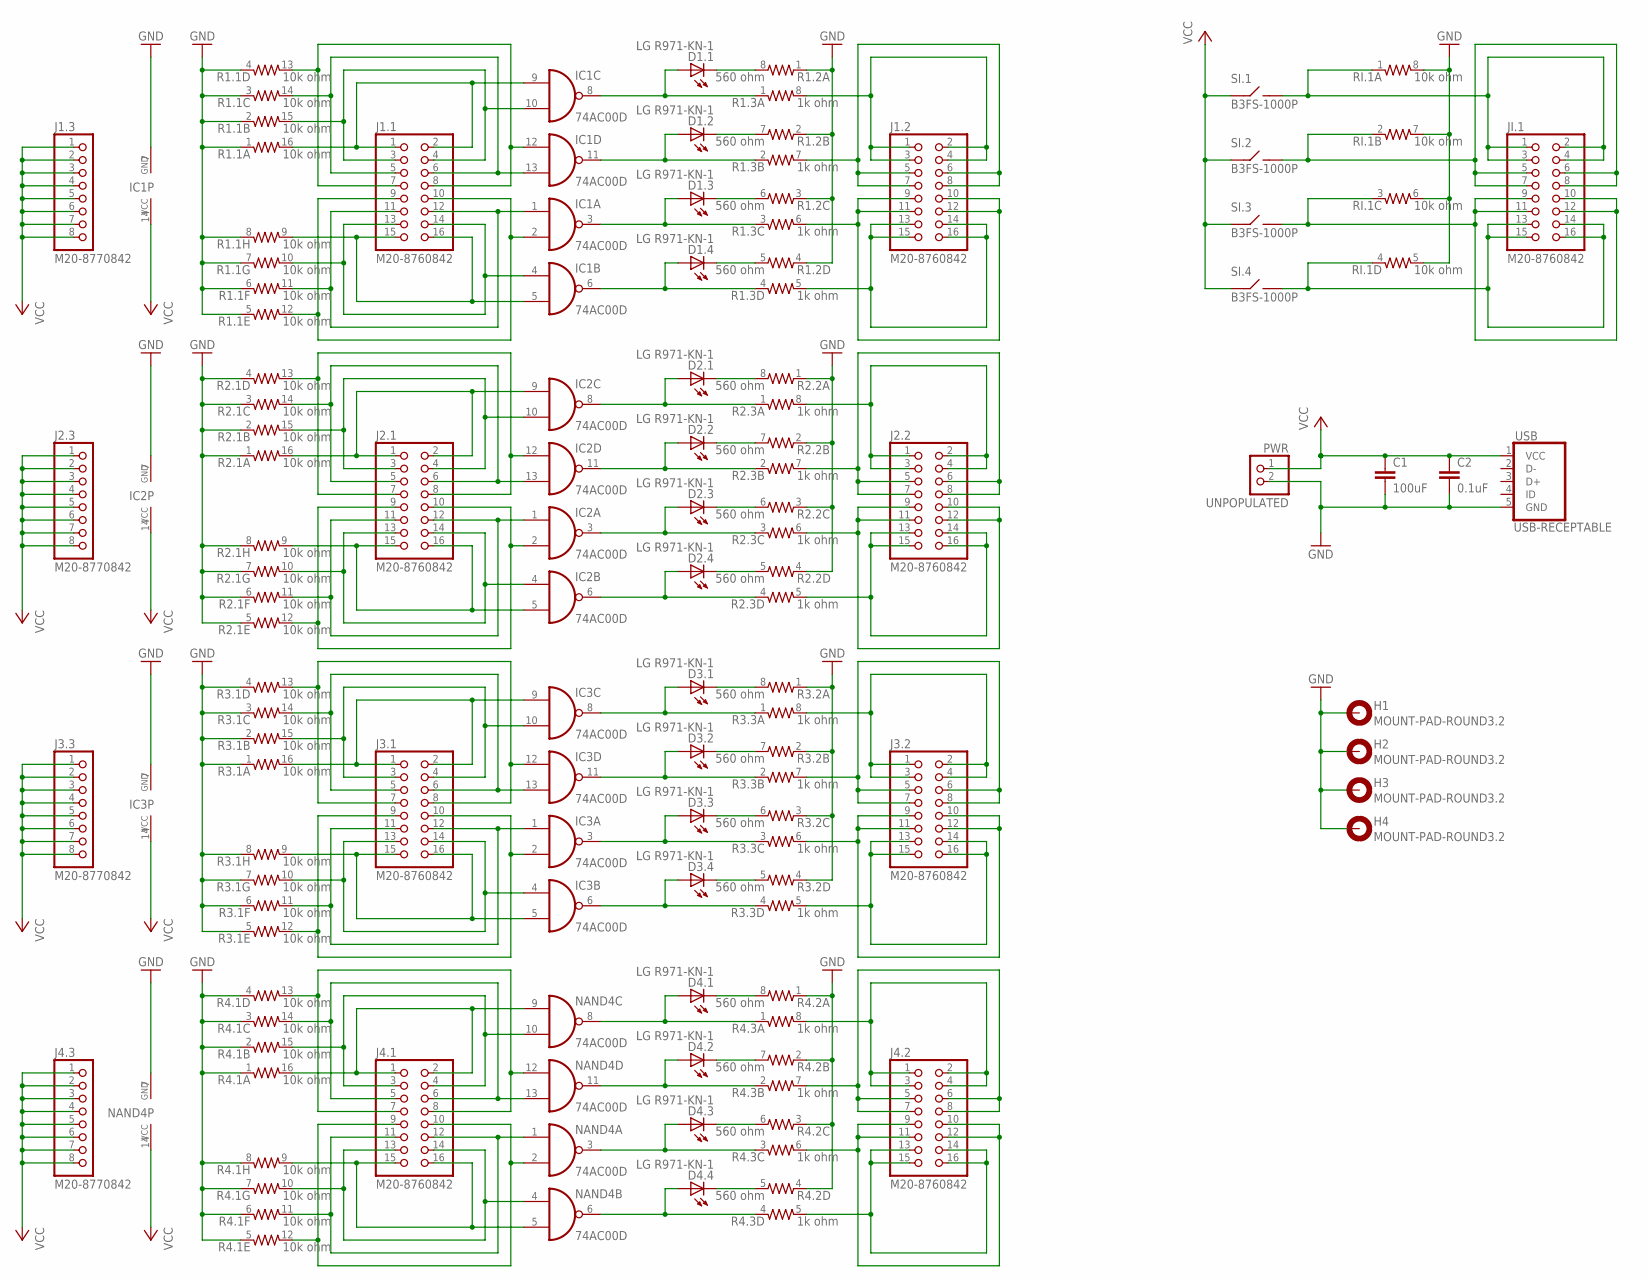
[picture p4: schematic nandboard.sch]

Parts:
C1: 100uF; C1210
C2: 0.1uF; C0805
D1.1, D1.2, D1.3, D1.4, D2.1, D2.2, D2.3, D2.4, D3.1, D3.2, D3.3, D3.4, D4.1, D4.2, D4.3, D4.4: LG R971-KN-1; CHIPLED_0805
H1, H2, H3, H4: MOUNT-PAD-ROUND3.2; 3,2-PAD
IC1, IC2, IC3: 74AC00D; SO14
J1.1, J1.2, J2.1, J2.2, J3.1, J3.2, J4.1, J4.2: M20-8760842; 2X08_SMT
J1.3, J2.3, J3.3, J4.3: M20-8770842; 1X08_SMT
JI.1: M20-8760842; 2X08_SMT
NAND4: 74AC00D; SO14
PWR: UNPOPULATED; 1X02
R1.1, R2.1, R3.1, R4.1: 10k ohm; 742-16
R1.2, R2.2, R3.2, R4.2: 560 ohm; 742-8
R1.3, R2.3, R3.3, R4.3: 1k ohm; 742-8
RI.1: 10k ohm; 742-8
SI.1, SI.2, SI.3, SI.4: B3FS-1000P; B3FS-1000
USB: USB-RECEPTABLE; FCI-10103594-0001LF

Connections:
GND: C1.2, C2.2, H1.B3,2, H2.B3,2, H3.B3,2, H4.B3,2, IC1.7 (GND), IC2.7 (GND), IC3.7 (GND), NAND4.7 (GND), PWR.2, R1.1.1, R1.1.2 (1), R1.1.3 (1), R1.1.4 (1), R1.1.5 (1), R1.1.6 (1), R1.1.7 (1), R1.1.8 (1), R1.2.1, R1.2.2 (1), R1.2.3 (1), R1.2.4 (1), R2.1.1, R2.1.2 (1), R2.1.3 (1), R2.1.4 (1), R2.1.5 (1), R2.1.6 (1), R2.1.7 (1), R2.1.8 (1), R2.2.1, R2.2.2 (1), R2.2.3 (1), R2.2.4 (1), R3.1.1, R3.1.2 (1), R3.1.3 (1), R3.1.4 (1), R3.1.5 (1), R3.1.6 (1), R3.1.7 (1), R3.1.8 (1), R3.2.1, R3.2.2 (1), R3.2.3 (1), R3.2.4 (1), R4.1.1, R4.1.2 (1), R4.1.3 (1), R4.1.4 (1), R4.1.5 (1), R4.1.6 (1), R4.1.7 (1), R4.1.8 (1), R4.2.1, R4.2.2 (1), R4.2.3 (1), R4.2.4 (1), RI.1.5 (2), RI.1.6 (2), RI.1.7 (2), RI.1.8 (2), USB.5 (GND)
unnamed: IC2.9 (I0), J2.1.1, J2.1.2, R2.1.16 (2)
unnamed: IC2.10 (I1), J2.1.3, J2.1.4, R2.1.15 (2)
unnamed: JI.1.1, JI.1.2, JI.1.3, JI.1.4, RI.1.1, SI.1.3 (B), SI.1.4 (B)
unnamed: IC2.13 (I1), J2.1.5, J2.1.6, R2.1.14 (2)
unnamed: IC2.12 (I0), J2.1.7, J2.1.8, R2.1.13 (2)
unnamed: JI.1.5, JI.1.6, JI.1.7, JI.1.8, RI.1.2 (1), SI.2.3 (B), SI.2.4 (B)
unnamed: JI.1.9, JI.1.10, JI.1.11, JI.1.12, RI.1.3 (1), SI.3.3 (B), SI.3.4 (B)
unnamed: JI.1.13, JI.1.14, JI.1.15, JI.1.16, RI.1.4 (1), SI.4.3 (B), SI.4.4 (B)
unnamed: IC2.5 (I1), J2.1.15, J2.1.16, R2.1.9 (2)
unnamed: IC2.4 (I0), J2.1.13, J2.1.14, R2.1.10 (2)
unnamed: IC2.1 (I0), J2.1.11, J2.1.12, R2.1.11 (2)
unnamed: IC2.2 (I1), J2.1.9, J2.1.10, R2.1.12 (2)
unnamed: D1.4.C, R1.2.5 (2)
unnamed: D1.3.C, R1.2.6 (2)
unnamed: D1.2.C, R1.2.7 (2)
unnamed: D1.1.C, R1.2.8 (2)
unnamed: J2.2.13, J2.2.14, J2.2.15, J2.2.16, R2.3.5 (2)
unnamed: J2.2.9, J2.2.10, J2.2.11, J2.2.12, R2.3.6 (2)
unnamed: J2.2.1, J2.2.2, J2.2.3, J2.2.4, R2.3.8 (2)
unnamed: J2.2.5, J2.2.6, J2.2.7, J2.2.8, R2.3.7 (2)
unnamed: IC1.9 (I0), J1.1.1, J1.1.2, R1.1.16 (2)
unnamed: IC1.10 (I1), J1.1.3, J1.1.4, R1.1.15 (2)
unnamed: IC1.13 (I1), J1.1.5, J1.1.6, R1.1.14 (2)
unnamed: IC1.12 (I0), J1.1.7, J1.1.8, R1.1.13 (2)
unnamed: J1.2.13, J1.2.14, J1.2.15, J1.2.16, R1.3.5 (2)
unnamed: J1.2.9, J1.2.10, J1.2.11, J1.2.12, R1.3.6 (2)
unnamed: D1.1.A, IC1.8 (O), R1.3.1
unnamed: J1.2.1, J1.2.2, J1.2.3, J1.2.4, R1.3.8 (2)
unnamed: IC1.5 (I1), J1.1.15, J1.1.16, R1.1.9 (2)
unnamed: IC1.4 (I0), J1.1.13, J1.1.14, R1.1.10 (2)
unnamed: IC1.1 (I0), J1.1.11, J1.1.12, R1.1.11 (2)
unnamed: IC1.2 (I1), J1.1.9, J1.1.10, R1.1.12 (2)
unnamed: D1.2.A, IC1.11 (O), R1.3.2 (1)
unnamed: J1.2.5, J1.2.6, J1.2.7, J1.2.8, R1.3.7 (2)
unnamed: D1.3.A, IC1.3 (O), R1.3.3 (1)
unnamed: D1.4.A, IC1.6 (O), R1.3.4 (1)
unnamed: D2.1.A, IC2.8 (O), R2.3.1
unnamed: D2.2.A, IC2.11 (O), R2.3.2 (1)
unnamed: D2.3.A, IC2.3 (O), R2.3.3 (1)
unnamed: D2.4.A, IC2.6 (O), R2.3.4 (1)
unnamed: D2.1.C, R2.2.8 (2)
unnamed: D2.2.C, R2.2.7 (2)
unnamed: D2.3.C, R2.2.6 (2)
unnamed: D2.4.C, R2.2.5 (2)
unnamed: IC3.9 (I0), J3.1.1, J3.1.2, R3.1.16 (2)
unnamed: IC3.10 (I1), J3.1.3, J3.1.4, R3.1.15 (2)
unnamed: IC3.13 (I1), J3.1.5, J3.1.6, R3.1.14 (2)
unnamed: IC3.12 (I0), J3.1.7, J3.1.8, R3.1.13 (2)
unnamed: IC3.5 (I1), J3.1.15, J3.1.16, R3.1.9 (2)
unnamed: IC3.4 (I0), J3.1.13, J3.1.14, R3.1.10 (2)
unnamed: IC3.1 (I0), J3.1.11, J3.1.12, R3.1.11 (2)
unnamed: IC3.2 (I1), J3.1.9, J3.1.10, R3.1.12 (2)
unnamed: J3.2.13, J3.2.14, J3.2.15, J3.2.16, R3.3.5 (2)
unnamed: J3.2.9, J3.2.10, J3.2.11, J3.2.12, R3.3.6 (2)
unnamed: J3.2.1, J3.2.2, J3.2.3, J3.2.4, R3.3.8 (2)
unnamed: J3.2.5, J3.2.6, J3.2.7, J3.2.8, R3.3.7 (2)
unnamed: D3.1.A, IC3.8 (O), R3.3.1
unnamed: D3.2.A, IC3.11 (O), R3.3.2 (1)
unnamed: D3.3.A, IC3.3 (O), R3.3.3 (1)
unnamed: D3.4.A, IC3.6 (O), R3.3.4 (1)
unnamed: D3.4.C, R3.2.5 (2)
unnamed: D3.3.C, R3.2.6 (2)
unnamed: D3.2.C, R3.2.7 (2)
unnamed: D3.1.C, R3.2.8 (2)
unnamed: J4.1.1, J4.1.2, NAND4.9 (I0), R4.1.16 (2)
unnamed: J4.1.3, J4.1.4, NAND4.10 (I1), R4.1.15 (2)
unnamed: J4.1.5, J4.1.6, NAND4.13 (I1), R4.1.14 (2)
unnamed: J4.1.7, J4.1.8, NAND4.12 (I0), R4.1.13 (2)
unnamed: J4.1.15, J4.1.16, NAND4.5 (I1), R4.1.9 (2)
unnamed: J4.1.13, J4.1.14, NAND4.4 (I0), R4.1.10 (2)
unnamed: J4.1.11, J4.1.12, NAND4.1 (I0), R4.1.11 (2)
unnamed: J4.1.9, J4.1.10, NAND4.2 (I1), R4.1.12 (2)
unnamed: J4.2.13, J4.2.14, J4.2.15, J4.2.16, R4.3.5 (2)
unnamed: J4.2.9, J4.2.10, J4.2.11, J4.2.12, R4.3.6 (2)
unnamed: J4.2.1, J4.2.2, J4.2.3, J4.2.4, R4.3.8 (2)
unnamed: J4.2.5, J4.2.6, J4.2.7, J4.2.8, R4.3.7 (2)
unnamed: D4.1.A, NAND4.8 (O), R4.3.1
unnamed: D4.2.A, NAND4.11 (O), R4.3.2 (1)
unnamed: D4.3.A, NAND4.3 (O), R4.3.3 (1)
unnamed: D4.4.A, NAND4.6 (O), R4.3.4 (1)
unnamed: D4.1.C, R4.2.8 (2)
unnamed: D4.2.C, R4.2.7 (2)
unnamed: D4.3.C, R4.2.6 (2)
unnamed: D4.4.C, R4.2.5 (2)
VCC: C1.1, C2.1, IC1.14 (VCC), IC2.14 (VCC), IC3.14 (VCC), J1.3.1, J1.3.2, J1.3.3, J1.3.4, J1.3.5, J1.3.6, J1.3.7, J1.3.8, J2.3.1, J2.3.2, J2.3.3, J2.3.4, J2.3.5, J2.3.6, J2.3.7, J2.3.8, J3.3.1, J3.3.2, J3.3.3, J3.3.4, J3.3.5, J3.3.6, J3.3.7, J3.3.8, J4.3.1, J4.3.2, J4.3.3, J4.3.4, J4.3.5, J4.3.6, J4.3.7, J4.3.8, NAND4.14 (VCC), PWR.1, SI.1.1 (A), SI.1.2 (A), SI.2.1 (A), SI.2.2 (A), SI.3.1 (A), SI.3.2 (A), SI.4.1 (A), SI.4.2 (A), USB.1 (VCC)

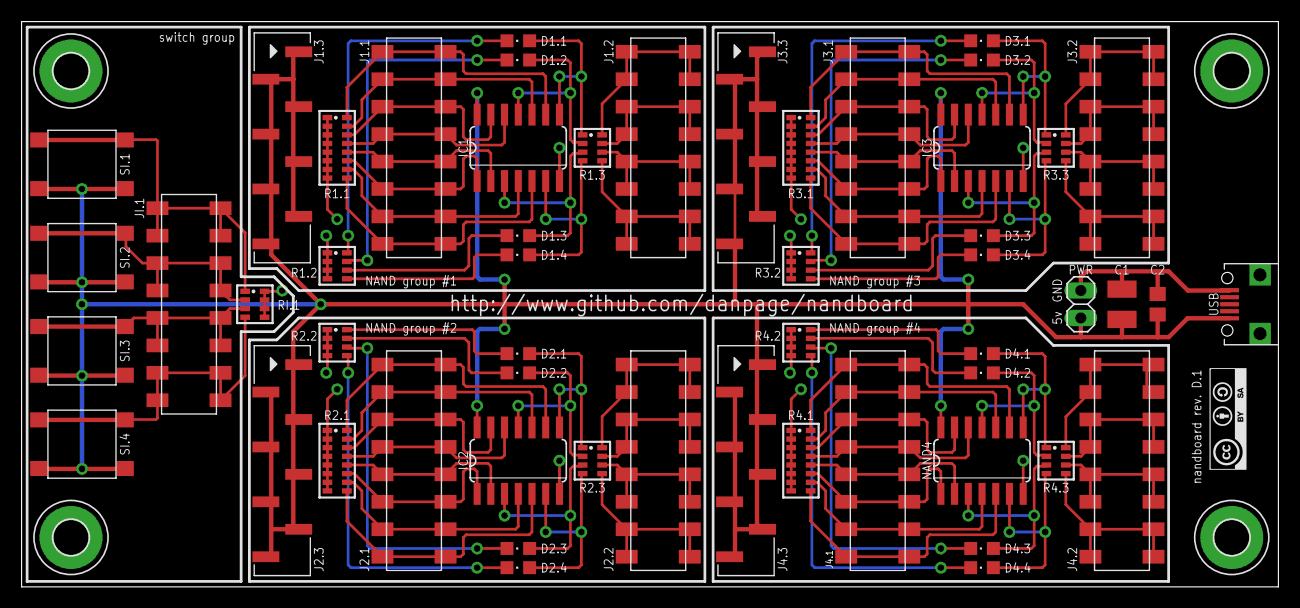
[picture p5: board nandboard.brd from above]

Board: 2 copper layers, 116.3 x 52.3 mm, 58 parts (0 on the bottom side), 86 nets.

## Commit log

2015-10-05 initial commit of rev. D design, plus fleshed out README.txt etc.
    [nandboard.brd, nandboard.csv, nandboard.sch]
2017-04-12 updated to rev. E design, moved to Octopart-based BOM, improved README.md
    [nandboard-pcb_rev_d.brd, nandboard-pcb_rev_d.sch, nandboard-pcb_rev_e.brd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]
2017-04-12 clean-up of older files
    [nandboard.brd, nandboard.csv, nandboard.sch]
2017-04-13 fixed a couple of markdown glitches
2017-07-06 updated README.md to include OSH Park PCB link
2017-07-20 added CSV-based BOMs (replicating Octopart BOM offline)
    [nandboard-pcb_rev_d.csv, nandboard-pcb_rev_e.csv]
2017-08-16 reorganised design files; improved photography a little
    [nandboard.brd, nandboard.csv, nandboard.sch]
2018-05-31 fixed typos in URLs; added schematic PDFs
2021-11-09 Update README.md
    https://forum.kicad.info/t/warning-avoid-all-links-to-kicad-pcb-org-use-kicad-org/31521
2024-09-13 add rev. F; remove rev. E; restructure user guide(s); rewrite PDF generator(s)
    [nandboard.brd, nandboard.csv, nandboard.kicad_pcb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]
2024-09-20 update PCB photo with better version

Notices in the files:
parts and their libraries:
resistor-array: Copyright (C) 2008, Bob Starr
